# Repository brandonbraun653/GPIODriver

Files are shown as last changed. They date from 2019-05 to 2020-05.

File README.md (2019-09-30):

# GPIODriver

This project is intended to provide a low-cost USB tethered HW/SW solution for controlling a large amount of discrete IO
signals at standard aircraft voltage levels (28vdc). More will be added here as the project matures. Currently in the
prototyping phase for both the hardware and the software.

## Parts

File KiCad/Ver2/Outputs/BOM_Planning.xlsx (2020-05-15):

Description | Part Name | Package | LCSC P/N | MFR P/N | Comment
PNP Transistor (600mA, 150V) | MMBT5401 | SOT-23 | C8326 (https://lcsc.com/product-detail/Transistors-NPN-PNP_Changjiang-Electronics-Tech-CJ-MMBT5401_C8326.html/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) | MMBT5401
NPN Transistor (600mA, 160V) | MMBT5551 | SOT-23 | C2145 (https://lcsc.com/product-detail/Transistors-NPN-PNP_Changjiang-Electronics-Tech-CJ-MMBT5551_C2145.html/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) | MMBT5551
Optocouple | EL357N | SOP-4 | C29981 (https://lcsc.com/product-detail/SMD-Optocouplers_EL357N-C-TA-G_C29981.html/?href=jlc-SMT) | EL357N(C)(TA)-G | Might need to find a smaller optocouple that is a basic component
GPIO Sense SR (Parallel In/Serial Out) | 74HC165 | SOIC-16 | C5613 (https://lcsc.com/product-detail/74-Series_Nexperia_74HC165D-653_74HC165D-653_C5613.html/?href=jlc-SMT) | 74HC165D,653
GPIO Out HI Drive (Shift Register) | 74HC595 | SOIC-16 | C5947 (https://lcsc.com/product-detail/74-Series_Nexperia-74HC595D-118_C5947.html/?href=jlc-SMT) | 74HC595,118
GPIO Out LO Drive (Shift Register) | 74HC595 | SOIC-16 | C5947 (https://lcsc.com/product-detail/74-Series_Nexperia-74HC595D-118_C5947.html/?href=jlc-SMT) | 74HC595,119
Octal Buffer | 74HC244 | TSSOP-20 | C5623 (https://lcsc.com/product-detail/74-Series_Nexperia-74HC244PW-118_C5623.html) | 74HC244PW,118
Digital Switch IC | 74LVC1G3157 | SC-88 | C426706 (https://lcsc.com/product-detail/Signal-Switches-Multiplexers-Decoders_Nexperia-74LVC1G3157GW-125_C426706.html) | 74LVC1G3157GW,125
Rectification Diodes | 1N4007 | SOD-123F | C108803 (https://lcsc.com/product-detail/Diodes-General-Purpose_Shandong-Jingdao-Microelectronics-1N4007W_C108803.html) | 1N4007W
High Voltage Drive Switch | AOD409 | TO-252-2(DPAK) | C36220 (https://lcsc.com/product-detail/MOSFET_Alpha-Omega-Semicon_AOD409_Alpha-Omega-Semicon-AOS-AOD409_C36220.html) | AOD409
Board To Board Connector (Male) |  |  | C59981 (https://lcsc.com/product-detail/Pin-Header-Female-Header_BOOMELE-Boom-Precision-Elec-C59981_C59981.html)
Board To Board Connector (Female) |  |  | C124397 (https://lcsc.com/product-detail/Pin-Header-Female-Header_Ckmtw-Shenzhen-Cankemeng-C124397_C124397.html)

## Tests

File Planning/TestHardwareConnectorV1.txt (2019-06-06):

Expected Connections:
    - +3.3v Power, 5W max
    - +5.0v Power, 5W max
    - +12.0v Power, 10W max
    - Power Ground
    - Signal Ground
    - UART x2
    - SPI x1, 3 chip selects
    - I2C x2
    - 5 GPIO
    - 3-pin resistor ID variant (place near the first few pins)

Minimum # of Pins: 27

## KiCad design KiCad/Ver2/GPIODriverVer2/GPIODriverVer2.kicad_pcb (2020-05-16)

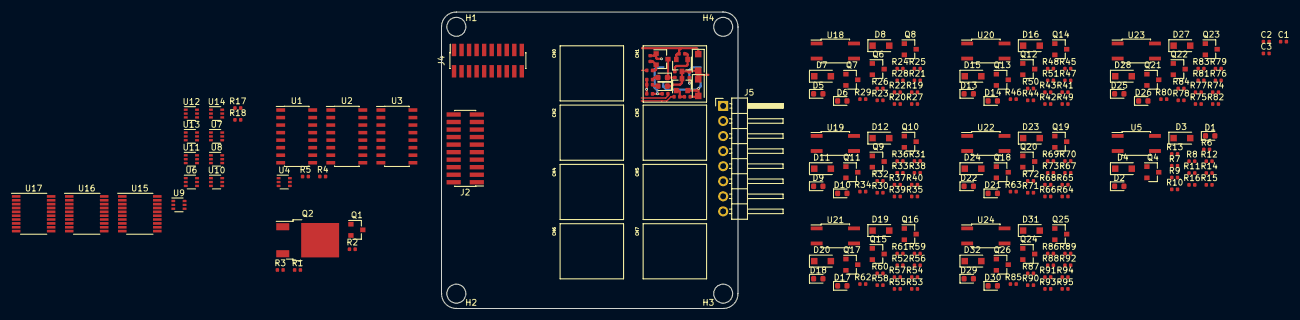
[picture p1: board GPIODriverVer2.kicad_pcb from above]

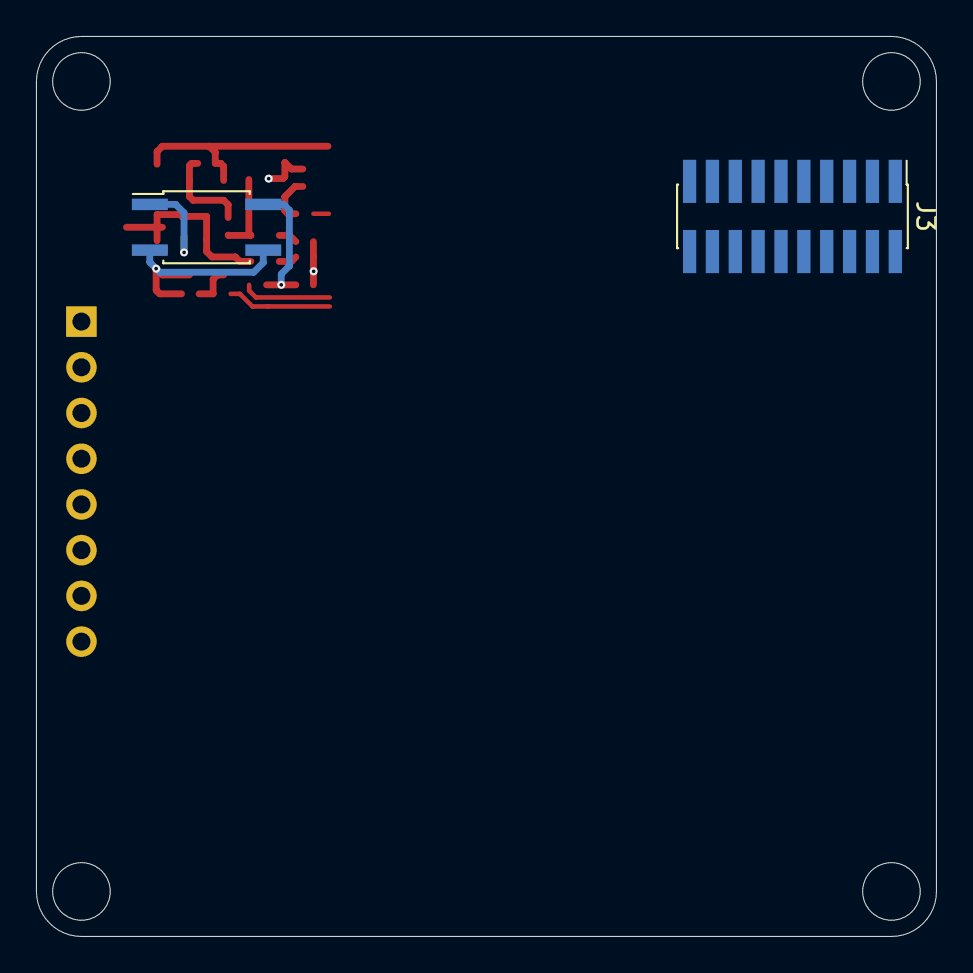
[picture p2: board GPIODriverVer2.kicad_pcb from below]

Board: 4 copper layers, 50.0 x 50.0 mm, 205 parts (2 on the bottom side), 113 nets.

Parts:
C1, C2, C3: 100nF; C_0402_1005Metric
D1, D1#2, D5, D9, D13, D17, D21, D25, D29: LED_HI_DRIVE_EN; D_0603_1608Metric
D2, D2#2, D6, D10, D14, D18, D22, D26, D30: LED_LO_DRIVE_EN; D_0603_1608Metric
D3, D3#2, D4, D4#2, D7, D8, D11, D12, D15, D16, D19, D20, D23, D24, D27, D28, D31, D32: 1N4007; D_SOD-123F
H1, H2, H3, H4: MountingHole_Pad; MountingHole_3.2mm_M3
J2: ExtInputs; PinHeader_2x10_P1.27mm_Vertical_SMD
J3: DaisyChainInput; PinHeader_2x10_P1.27mm_Vertical_SMD
J4: DaisyChainOutput; PinSocket_2x10_P1.27mm_Vertical_SMD
J5: DriveOutput; PinHeader_1x08_P2.54mm_Horizontal
Q1, Q3, Q6, Q9, Q12, Q15, Q18, Q21, Q24: 2N3904; SOT-23
Q2: AOD409; TO-252-2
Q4, Q4#2, Q7, Q10, Q13, Q16, Q19, Q22, Q25: MMBT5401; SOT-23
Q5, Q8, Q11, Q14, Q17, Q20, Q23, Q26: MMBT5551L; SOT-23
R1, R7, R7#2, R9, R9#2, R13, R13#2, R20, R22, R26, R31, R33, R37, R42, R44, R48, R53, R55, R59, R64, R66, R70, R75, R77, R81, R86, R88, R92: 100; R_0402_1005Metric
R2, R3, R4, R5, R8, R8#2, R10, R10#2, R14, R14#2, R15, R15#2, R17, R18, R21, R23, R27, R28, R32, R34, R38, R39, R43, R45, R49, R50, R54, R56, R60, R61, R65, R67, R71, R72, R76, R78, R82, R83, R87, R89, R93, R94: 10k; R_0402_1005Metric
R6, R6#2, R12, R12#2, R19, R25, R30, R36, R41, R47, R52, R58, R63, R69, R74, R80, R85, R91: 1.8k; R_0402_1005Metric
R11, R11#2, R24, R35, R46, R57, R68, R79, R90: 500; R_0402_1005Metric
R16, R16#2, R29, R40, R51, R62, R73, R84, R95: 5.6k; R_0402_1005Metric
U1: SR_WRITE_HI; SOIC-16_3.9x9.9mm_P1.27mm
U2: SR_WRITE_LO; SOIC-16_3.9x9.9mm_P1.27mm
U3: SR_READ_STATE; SOIC-16_3.9x9.9mm_P1.27mm
U4, U6, U7, U8, U9, U10, U11, U12, U13, U14: 74LVC1G3157; SOT-363_SC-70-6
U5, U5#2, U18, U19, U20, U21, U22, U23, U24: LTV-357T; SO-4_4.4x3.6mm_P2.54mm
U15, U16, U17: 74HC244; TSSOP-20_4.4x6.5mm_P0.65mm

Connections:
/DriveCircuitry/DriveChannel0/DriveOutput: D30.1, D31.2, D32.1, J5.1, Q25.3, Q26.3, R95.2
/DriveCircuitry/DriveChannel1/DriveOutput: D2.1, D2#2.1, D3.2, D3#2.2, D4.1, D4#2.1, J5.2, Q4.3, Q4#2.3, Q5.3, R16.2, R16#2.2
/DriveCircuitry/DriveChannel2/DriveOutput: D6.1, D7.2, D8.1, J5.3, Q7.3, Q8.3, R29.2
/DriveCircuitry/DriveChannel3/DriveOutput: D10.1, D11.2, D12.1, J5.4, Q10.3, Q11.3, R40.2
/DriveCircuitry/DriveChannel4/DriveOutput: D14.1, D15.2, D16.1, J5.5, Q13.3, Q14.3, R51.2
/DriveCircuitry/DriveChannel5/DriveOutput: D18.1, D19.2, D20.1, J5.6, Q16.3, Q17.3, R62.2
/DriveCircuitry/DriveChannel6/DriveOutput: D22.1, D23.2, D24.1, J5.7, Q19.3, Q20.3, R73.2
/DriveCircuitry/DriveChannel7/DriveOutput: D26.1, D27.2, D28.1, J5.8, Q22.3, Q23.3, R84.2
/InputCircuitry/EXT_3V3_PWR: J4.13, J4.15
/InputCircuitry/EXT_5V_PWR: J4.1, J4.3
/InputCircuitry/EXT_HV_PWR: J4.7, J4.9
/InputCircuitry/INT_OUTPUT_DRIVE_EN: U1.13, U2.13
/InputCircuitry/INT_SPI_RW_MOSI: U1.14, U2.14
/InputCircuitry/INT_SPI_RW_SCK: U1.11, U2.11, U3.2
/InputCircuitry/INT_SPI_W_CS_HI_DRIVE: U1.12, U4.6
CH0_HI_EN: R86.2, U1.15
CH0_LO_EN: R92.2, U2.15
CH0_STATE: R88.2, U3.11
CH1_HI_EN: R7.2, R7#2.2, U1.1
CH1_LO_EN: R13.2, R13#2.2, U2.1
CH1_STATE: R9.2, R9#2.2, U3.12
CH2_HI_EN: R20.2, U1.2
CH2_LO_EN: R26.2, U2.2
CH2_STATE: R22.2, U3.13
CH3_HI_EN: R31.2, U1.3
CH3_LO_EN: R37.2, U2.3
CH3_STATE: R33.2, U3.14
CH4_HI_EN: R42.2, U1.4
CH4_LO_EN: R48.2, U2.4
CH4_STATE: R44.2, U3.3
CH5_HI_EN: R53.2, U1.5
CH5_LO_EN: R59.2, U2.5
CH5_STATE: R55.2, U3.4
CH6_HI_EN: R64.2, U1.6
CH6_LO_EN: R70.2, U2.6
CH6_STATE: R66.2, U3.5
CH7_HI_EN: R75.2, U1.7
CH7_LO_EN: R81.2, U2.7
CH7_STATE: R77.2, U3.6
GND: C1.1, C2.1, C3.1, D4.2, D4#2.2, D8.2, D12.2, D16.2, D20.2, D24.2, D28.2, D32.2, H1.1, H2.1, H3.1, H4.1, J4.5, J4.11, J4.17, Q1.1, Q3.1, Q5.2, Q6.1, Q8.2, Q9.1, Q11.2, Q12.1, Q14.2, Q15.1, Q17.2, Q18.1, Q20.2, Q21.1, Q23.2, Q24.1, Q26.2, R3.1, R8.2, R8#2.2, R15.2, R15#2.2, R18.2, R21.2, R28.2, R32.2, R39.2, R43.2, R50.2, R54.2, R61.2, R65.2, R72.2, R76.2, R83.2, R87.2, R94.2, U1.8, U2.8, U3.8, U4.2, U5.2, U5.3, U5#2.2, U5#2.3, U6.2, U7.2, U8.2, U9.2, U10.2, U11.2, U12.2, U13.2, U14.2, U18.2, U18.3, U19.2, U19.3, U20.2, U20.3, U21.2, U21.3, U22.2, U22.3, U23.2, U23.3, U24.2, U24.3
unnamed: D1.1, D1#2.1, Q3.3, R11.2, R11#2.2
unnamed: D1.2, D1#2.2, R6.1, R6#2.1
unnamed: D2.2, D2#2.2, R12.2, R12#2.2
unnamed: D5.1, Q6.3, R24.2
unnamed: D5.2, R19.1
unnamed: D6.2, R25.2
unnamed: D9.1, Q9.3, R35.2
unnamed: D9.2, R30.1
unnamed: D10.2, R36.2
unnamed: D13.1, Q12.3, R46.2
unnamed: D13.2, R41.1
unnamed: D14.2, R47.2
unnamed: D17.1, Q15.3, R57.2
unnamed: D17.2, R52.1
unnamed: D18.2, R58.2
unnamed: D21.1, Q18.3, R68.2
unnamed: D21.2, R63.1
unnamed: D22.2, R69.2
unnamed: D25.1, Q21.3, R79.2
unnamed: D25.2, R74.1
unnamed: D26.2, R80.2
unnamed: D29.1, Q24.3, R90.2
unnamed: D29.2, R85.1
unnamed: D30.2, R91.2
unnamed: Q1.2, R1.2, R3.2
unnamed: Q1.3, Q2.2, R2.1
unnamed: Q3.2, R7.1, R7#2.1, R8.1, R8#2.1
unnamed: Q4.1, Q4#2.1, R11.1, R11#2.1, R14.2, R14#2.2
unnamed: Q5.1, R13.1, R13#2.1, R15.1, R15#2.1
unnamed: Q6.2, R20.1, R21.1
unnamed: Q7.1, R24.1, R27.2
unnamed: Q8.1, R26.1, R28.1
unnamed: Q9.2, R31.1, R32.1
unnamed: Q10.1, R35.1, R38.2
unnamed: Q11.1, R37.1, R39.1
unnamed: Q12.2, R42.1, R43.1
unnamed: Q13.1, R46.1, R49.2
unnamed: Q14.1, R48.1, R50.1
unnamed: Q15.2, R53.1, R54.1
unnamed: Q16.1, R57.1, R60.2
unnamed: Q17.1, R59.1, R61.1
unnamed: Q18.2, R64.1, R65.1
unnamed: Q19.1, R68.1, R71.2
unnamed: Q20.1, R70.1, R72.1
unnamed: Q21.2, R75.1, R76.1
unnamed: Q22.1, R79.1, R82.2
unnamed: Q23.1, R81.1, R83.1
unnamed: Q24.2, R86.1, R87.1
unnamed: Q25.1, R90.1, R93.2
unnamed: Q26.1, R92.1, R94.1
unnamed: R4.1, U2.10
unnamed: R5.1, U1.10
unnamed: R9.1, R9#2.1, R10.2, R10#2.2, U5.4, U5#2.4
unnamed: R16.1, R16#2.1, U5.1, U5#2.1
unnamed: R22.1, R23.2, U18.4
unnamed: R29.1, U18.1
unnamed: R33.1, R34.2, U19.4
unnamed: R40.1, U19.1
unnamed: R44.1, R45.2, U20.4
unnamed: R51.1, U20.1
unnamed: R55.1, R56.2, U21.4
unnamed: R62.1, U21.1
unnamed: R66.1, R67.2, U22.4
unnamed: R73.1, U22.1
unnamed: R77.1, R78.2, U23.4
unnamed: R84.1, U23.1
unnamed: R88.1, R89.2, U24.4
unnamed: R95.1, U24.1
unnamed: U1.9, U4.3
unnamed: U2.9, U4.1
SRC_SELECT: U6.6, U7.6, U8.6, U9.6, U10.6, U11.6, U12.6, U13.6, U14.6
VBUS: D3.1, D3#2.1, D7.1, D11.1, D15.1, D19.1, D23.1, D27.1, D31.1, Q2.1, Q4.2, Q4#2.2, Q7.2, Q10.2, Q13.2, Q16.2, Q19.2, Q22.2, Q25.2, R14.1, R14#2.1, R27.1, R38.1, R49.1, R60.1, R71.1, R82.1, R93.1
VCC: C1.2, C2.2, C3.2, Q2.3, R2.2, R4.2, R5.2, R6.2, R6#2.2, R10.1, R10#2.1, R12.1, R12#2.1, R17.1, R19.2, R23.1, R25.1, R30.2, R34.1, R36.1, R41.2, R45.1, R47.1, R52.2, R56.1, R58.1, R63.2, R67.1, R69.1, R74.2, R78.1, R80.1, R85.2, R89.1, R91.1, U1.16, U2.16, U3.16, U4.5, U6.5, U7.5, U8.5, U9.5, U10.5, U11.5, U12.5, U13.5, U14.5

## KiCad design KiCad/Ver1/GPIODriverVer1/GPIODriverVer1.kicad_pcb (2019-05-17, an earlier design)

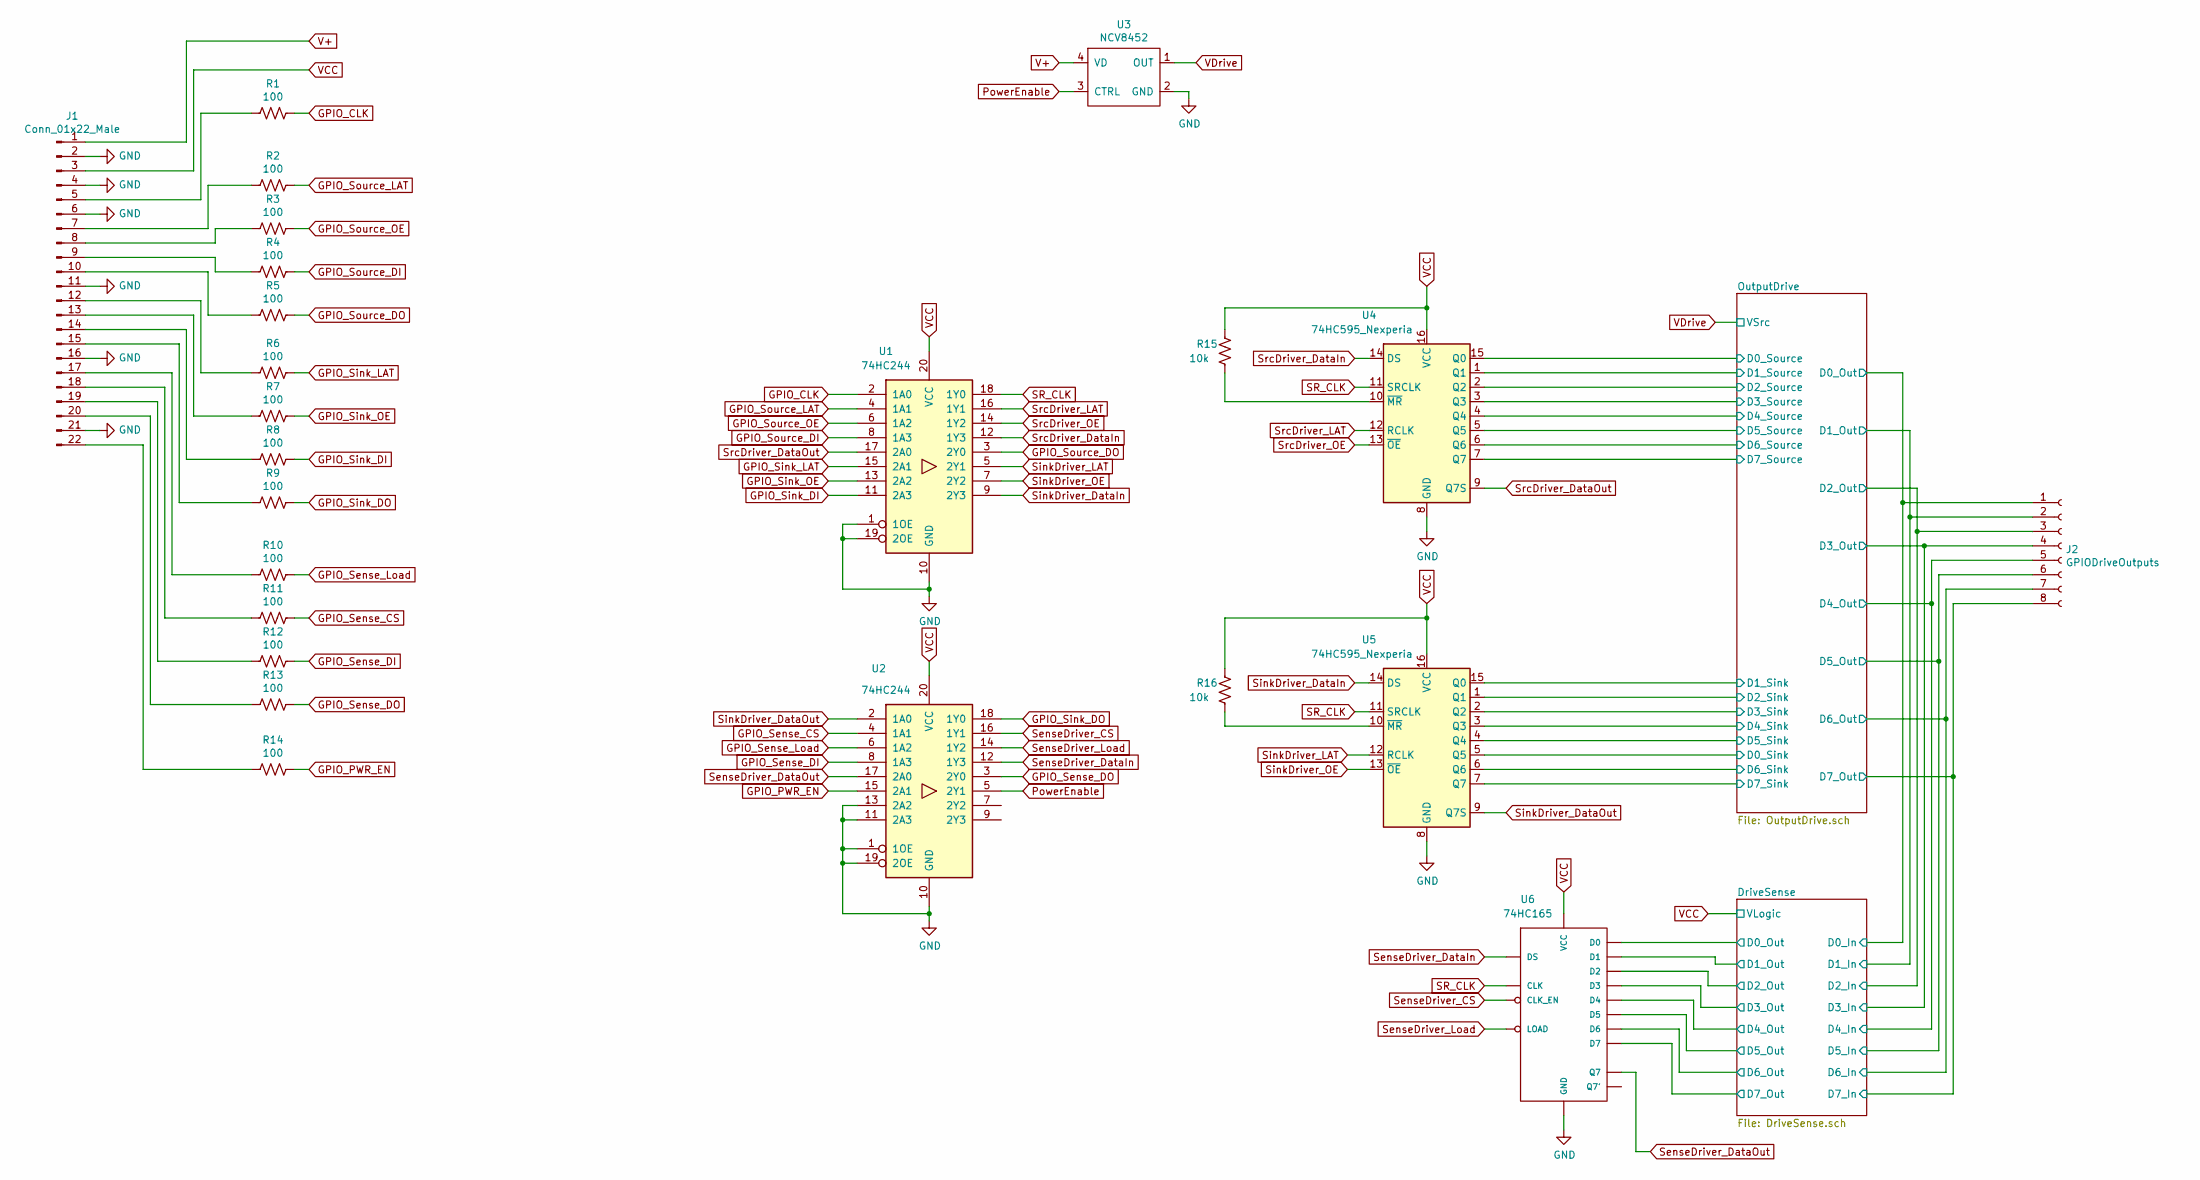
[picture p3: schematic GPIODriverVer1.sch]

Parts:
J1: Conn_01x22_Male; PinHeader_2x11_P2.54mm_Vertical
J2: GPIODriveOutputs; PinHeader_1x08_P2.54mm_Horizontal
R1, R2, R3, R4, R5, R6, R7, R8, R9, R10, R11, R12, R13, R14: 100; R_0402_1005Metric
R15, R16: 10k; R_0402_1005Metric
U1, U2: 74HC244; TSSOP-20_4.4x6.5mm_P0.65mm
U3: NCV8452; SOT-223
U4, U5: 74HC595_Nexperia; TSSOP-16_4.4x5mm_P0.65mm
U6: 74HC165; TSSOP-16_4.4x5mm_P0.65mm

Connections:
/DriveSense/D0_In: J2.1; also elsewhere on the board
/DriveSense/D0_Out: U6.11 (D0); also elsewhere on the board
/DriveSense/D1_In: J2.2; also elsewhere on the board
/DriveSense/D1_Out: U6.12 (D1); also elsewhere on the board
/DriveSense/D2_In: J2.3; also elsewhere on the board
/DriveSense/D2_Out: U6.13 (D2); also elsewhere on the board
/DriveSense/D3_In: J2.4; also elsewhere on the board
/DriveSense/D3_Out: U6.14 (D3); also elsewhere on the board
/DriveSense/D4_In: J2.5; also elsewhere on the board
/DriveSense/D4_Out: U6.3 (D4); also elsewhere on the board
/DriveSense/D5_In: J2.6; also elsewhere on the board
/DriveSense/D5_Out: U6.4 (D5); also elsewhere on the board
/DriveSense/D6_In: J2.7; also elsewhere on the board
/DriveSense/D6_Out: U6.5 (D6); also elsewhere on the board
/DriveSense/D7_In: J2.8; also elsewhere on the board
/DriveSense/D7_Out: U6.6 (D7); also elsewhere on the board
/OutputDrive/D0_Sink: U5.5 (Q5); also elsewhere on the board
/OutputDrive/D0_Source: U4.15 (Q0); also elsewhere on the board
/OutputDrive/D1_Sink: U5.15 (Q0); also elsewhere on the board
/OutputDrive/D1_Source: U4.1 (Q1); also elsewhere on the board
/OutputDrive/D2_Sink: U5.1 (Q1); also elsewhere on the board
/OutputDrive/D2_Source: U4.2 (Q2); also elsewhere on the board
/OutputDrive/D3_Sink: U5.2 (Q2); also elsewhere on the board
/OutputDrive/D3_Source: U4.3 (Q3); also elsewhere on the board
/OutputDrive/D4_Sink: U5.3 (Q3); also elsewhere on the board
/OutputDrive/D4_Source: U4.4 (Q4); also elsewhere on the board
/OutputDrive/D5_Sink: U5.4 (Q4); also elsewhere on the board
/OutputDrive/D5_Source: U4.5 (Q5); also elsewhere on the board
/OutputDrive/D6_Sink: U5.6 (Q6); also elsewhere on the board
/OutputDrive/D6_Source: U4.6 (Q6); also elsewhere on the board
/OutputDrive/D7_Sink: U5.7 (Q7); also elsewhere on the board
/OutputDrive/D7_Source: U4.7 (Q7); also elsewhere on the board
GND: J1.2, J1.4, J1.6, J1.11, J1.16, J1.21, U1.1 (1OE), U1.10 (GND), U1.19 (2OE), U2.1 (1OE), U2.10 (GND), U2.11 (2A3), U2.13 (2A2), U2.19 (2OE), U3.2 (GND), U4.8 (GND), U5.8 (GND), U6.8 (GND); also elsewhere on the board
GPIO_CLK: R1.1, U1.2 (1A0)
GPIO_PWR_EN: R14.1, U2.15 (2A1)
GPIO_Sense_CS: R11.1, U2.4 (1A1)
GPIO_Sense_DI: R12.1, U2.8 (1A3)
GPIO_Sense_DO: R13.1, U2.3 (2Y0)
GPIO_Sense_Load: R10.1, U2.6 (1A2)
GPIO_Sink_DI: R8.1, U1.11 (2A3)
GPIO_Sink_DO: R9.1, U2.18 (1Y0)
GPIO_Sink_LAT: R6.1, U1.15 (2A1)
GPIO_Sink_OE: R7.1, U1.13 (2A2)
GPIO_Source_DI: R4.1, U1.8 (1A3)
GPIO_Source_DO: R5.1, U1.3 (2Y0)
GPIO_Source_LAT: R2.1, U1.4 (1A1)
GPIO_Source_OE: R3.1, U1.6 (1A2)
unnamed: J1.5, R1.2
unnamed: J1.7, R2.2
unnamed: J1.8, R3.2
unnamed: J1.9, R4.2
unnamed: J1.10, R5.2
unnamed: J1.12, R6.2
unnamed: J1.13, R7.2
unnamed: J1.14, R8.2
unnamed: J1.15, R9.2
unnamed: J1.17, R10.2
unnamed: J1.18, R11.2
unnamed: J1.19, R12.2
unnamed: J1.20, R13.2
unnamed: J1.22, R14.2
unnamed: R15.1, U4.10 (~MR)
unnamed: R16.1, U5.10 (~MR)
PowerEnable: U2.5 (2Y1), U3.3 (CTRL)
SR_CLK: U1.18 (1Y0), U4.11 (SRCLK), U5.11 (SRCLK), U6.2 (CLK)
SenseDriver_CS: U2.16 (1Y1), U6.15 (CLK_EN)
SenseDriver_DataIn: U2.12 (1Y3), U6.10 (DS)
SenseDriver_DataOut: U2.17 (2A0), U6.9 (Q7)
SenseDriver_Load: U2.14 (1Y2), U6.1 (LOAD)
SinkDriver_DataIn: U1.9 (2Y3), U5.14 (DS)
SinkDriver_DataOut: U2.2 (1A0), U5.9 (Q7S)
SinkDriver_LAT: U1.5 (2Y1), U5.12 (RCLK)
SinkDriver_OE: U1.7 (2Y2), U5.13 (~OE)
SrcDriver_DataIn: U1.12 (1Y3), U4.14 (DS)
SrcDriver_DataOut: U1.17 (2A0), U4.9 (Q7S)
SrcDriver_LAT: U1.16 (1Y1), U4.12 (RCLK)
SrcDriver_OE: U1.14 (1Y2), U4.13 (~OE)
V+: J1.1, U3.4 (VD)
VCC: J1.3, R15.2, R16.2, U1.20 (VCC), U2.20 (VCC), U4.16 (VCC), U5.16 (VCC), U6.16 (VCC); also elsewhere on the board
VDrive: U3.1 (OUT); also elsewhere on the board

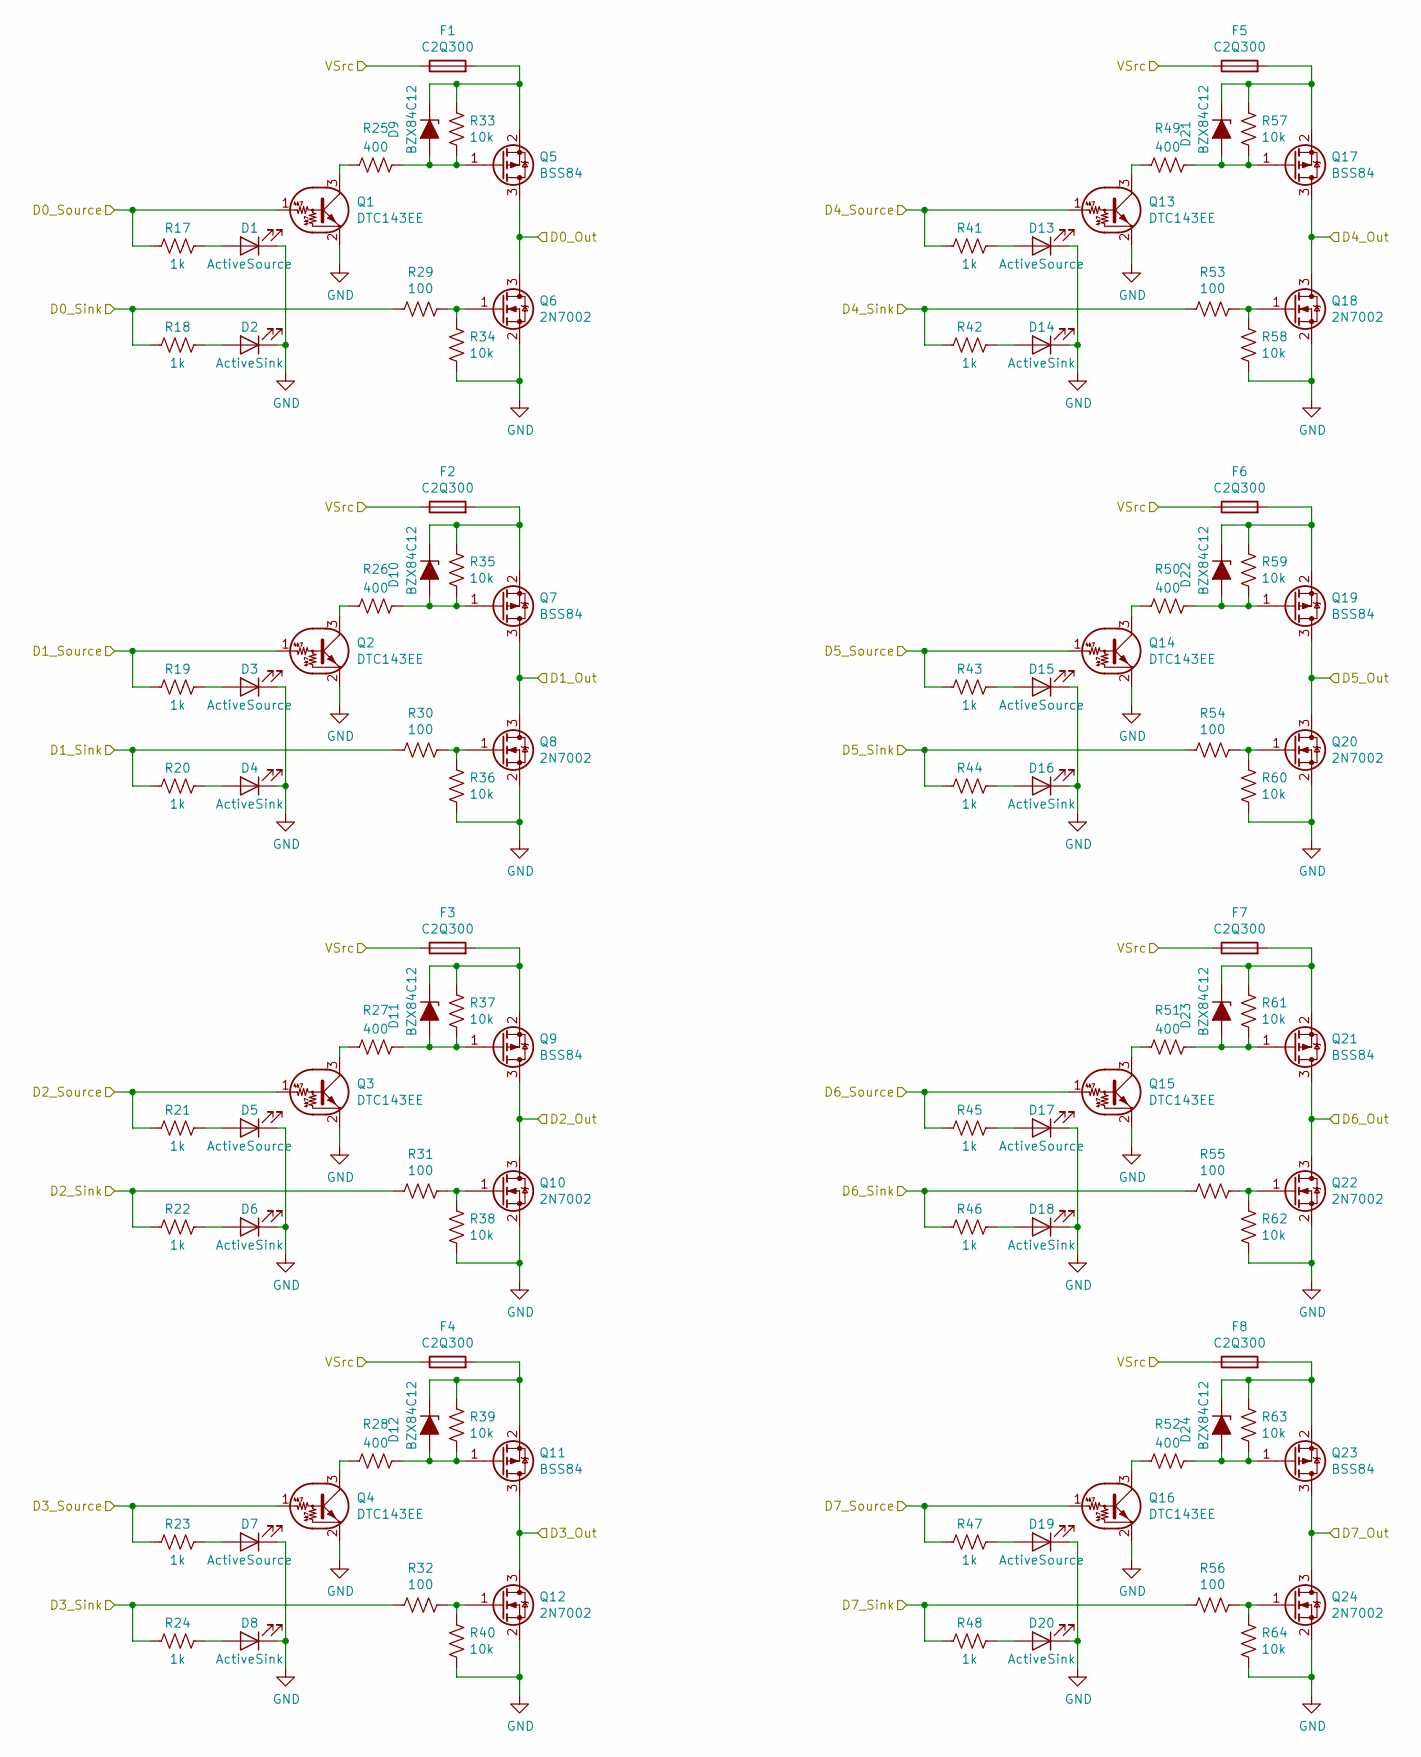
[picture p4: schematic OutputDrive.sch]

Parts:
D1, D3, D5, D7, D13, D15, D17, D19: ActiveSource; D_0603_1608Metric_Pad1.05x0.95mm_HandSolder
D2, D4, D6, D8, D14, D16, D18, D20: ActiveSink; D_0603_1608Metric_Pad1.05x0.95mm_HandSolder
D9, D10, D11, D12, D21, D22, D23, D24: BZX84C12; D_SOT-23_ANK
F1, F2, F3, F4, F5, F6, F7, F8: C2Q300; R_0603_1608Metric
Q1, Q2, Q3, Q4, Q13, Q14, Q15, Q16: DTC143EE; SOT-723
Q5, Q7, Q9, Q11, Q17, Q19, Q21, Q23: BSS84; SOT-323_SC-70
Q6, Q8, Q10, Q12, Q18, Q20, Q22, Q24: 2N7002; SOT-23
R17, R18, R19, R20, R21, R22, R23, R24, R41, R42, R43, R44, R45, R46, R47, R48: 1k; R_0402_1005Metric
R25, R26, R27, R28, R49, R50, R51, R52: 400; R_0402_1005Metric
R29, R30, R31, R32, R53, R54, R55, R56: 100; R_0402_1005Metric
R33, R34, R35, R36, R37, R38, R39, R40, R57, R58, R59, R60, R61, R62, R63, R64: 10k; R_0402_1005Metric

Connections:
/DriveSense/D0_In: Q5.3 (D), Q6.3 (D); also elsewhere on the board
/DriveSense/D1_In: Q7.3 (D), Q8.3 (D); also elsewhere on the board
/DriveSense/D2_In: Q9.3 (D), Q10.3 (D); also elsewhere on the board
/DriveSense/D3_In: Q11.3 (D), Q12.3 (D); also elsewhere on the board
/DriveSense/D4_In: Q17.3 (D), Q18.3 (D); also elsewhere on the board
/DriveSense/D5_In: Q19.3 (D), Q20.3 (D); also elsewhere on the board
/DriveSense/D6_In: Q21.3 (D), Q22.3 (D); also elsewhere on the board
/DriveSense/D7_In: Q23.3 (D), Q24.3 (D); also elsewhere on the board
/OutputDrive/D0_Sink: R18.2, R29.2; also elsewhere on the board
/OutputDrive/D0_Source: Q1.1 (B), R17.2; also elsewhere on the board
/OutputDrive/D1_Sink: R20.2, R30.2; also elsewhere on the board
/OutputDrive/D1_Source: Q2.1 (B), R19.2; also elsewhere on the board
/OutputDrive/D2_Sink: R22.2, R31.2; also elsewhere on the board
/OutputDrive/D2_Source: Q3.1 (B), R21.2; also elsewhere on the board
/OutputDrive/D3_Sink: R24.2, R32.2; also elsewhere on the board
/OutputDrive/D3_Source: Q4.1 (B), R23.2; also elsewhere on the board
/OutputDrive/D4_Sink: R42.2, R53.2; also elsewhere on the board
/OutputDrive/D4_Source: Q13.1 (B), R41.2; also elsewhere on the board
/OutputDrive/D5_Sink: R44.2, R54.2; also elsewhere on the board
/OutputDrive/D5_Source: Q14.1 (B), R43.2; also elsewhere on the board
/OutputDrive/D6_Sink: R46.2, R55.2; also elsewhere on the board
/OutputDrive/D6_Source: Q15.1 (B), R45.2; also elsewhere on the board
/OutputDrive/D7_Sink: R48.2, R56.2; also elsewhere on the board
/OutputDrive/D7_Source: Q16.1 (B), R47.2; also elsewhere on the board
GND: D1.1 (K), D2.1 (K), D3.1 (K), D4.1 (K), D5.1 (K), D6.1 (K), D7.1 (K), D8.1 (K), D13.1 (K), D14.1 (K), D15.1 (K), D16.1 (K), D17.1 (K), D18.1 (K), D19.1 (K), D20.1 (K), Q1.2 (E), Q2.2 (E), Q3.2 (E), Q4.2 (E), Q6.2 (S), Q8.2 (S), Q10.2 (S), Q12.2 (S), Q13.2 (E), Q14.2 (E), Q15.2 (E), Q16.2 (E), Q18.2 (S), Q20.2 (S), Q22.2 (S), Q24.2 (S), R34.1, R36.1, R38.1, R40.1, R58.1, R60.1, R62.1, R64.1; also elsewhere on the board
unnamed: D1.2 (A), R17.1
unnamed: D2.2 (A), R18.1
unnamed: D3.2 (A), R19.1
unnamed: D4.2 (A), R20.1
unnamed: D5.2 (A), R21.1
unnamed: D6.2 (A), R22.1
unnamed: D7.2 (A), R23.1
unnamed: D8.2 (A), R24.1
unnamed: D9.1 (K), F1.2, Q5.2 (S), R33.1
unnamed: D9.2 (A), Q5.1 (G), R25.2, R33.2
unnamed: D10.1 (K), F2.2, Q7.2 (S), R35.1
unnamed: D10.2 (A), Q7.1 (G), R26.2, R35.2
unnamed: D11.1 (K), F3.2, Q9.2 (S), R37.1
unnamed: D11.2 (A), Q9.1 (G), R27.2, R37.2
unnamed: D12.1 (K), F4.2, Q11.2 (S), R39.1
unnamed: D12.2 (A), Q11.1 (G), R28.2, R39.2
unnamed: D13.2 (A), R41.1
unnamed: D14.2 (A), R42.1
unnamed: D15.2 (A), R43.1
unnamed: D16.2 (A), R44.1
unnamed: D17.2 (A), R45.1
unnamed: D18.2 (A), R46.1
unnamed: D19.2 (A), R47.1
unnamed: D20.2 (A), R48.1
unnamed: D21.1 (K), F5.2, Q17.2 (S), R57.1
unnamed: D21.2 (A), Q17.1 (G), R49.2, R57.2
unnamed: D22.1 (K), F6.2, Q19.2 (S), R59.1
unnamed: D22.2 (A), Q19.1 (G), R50.2, R59.2
unnamed: D23.1 (K), F7.2, Q21.2 (S), R61.1
unnamed: D23.2 (A), Q21.1 (G), R51.2, R61.2
unnamed: D24.1 (K), F8.2, Q23.2 (S), R63.1
unnamed: D24.2 (A), Q23.1 (G), R52.2, R63.2
unnamed: Q1.3 (C), R25.1
unnamed: Q2.3 (C), R26.1
unnamed: Q3.3 (C), R27.1
unnamed: Q4.3 (C), R28.1
unnamed: Q6.1 (G), R29.1, R34.2
unnamed: Q8.1 (G), R30.1, R36.2
unnamed: Q10.1 (G), R31.1, R38.2
unnamed: Q12.1 (G), R32.1, R40.2
unnamed: Q13.3 (C), R49.1
unnamed: Q14.3 (C), R50.1
unnamed: Q15.3 (C), R51.1
unnamed: Q16.3 (C), R52.1
unnamed: Q18.1 (G), R53.1, R58.2
unnamed: Q20.1 (G), R54.1, R60.2
unnamed: Q22.1 (G), R55.1, R62.2
unnamed: Q24.1 (G), R56.1, R64.2
VDrive: F1.1, F2.1, F3.1, F4.1, F5.1, F6.1, F7.1, F8.1; also elsewhere on the board

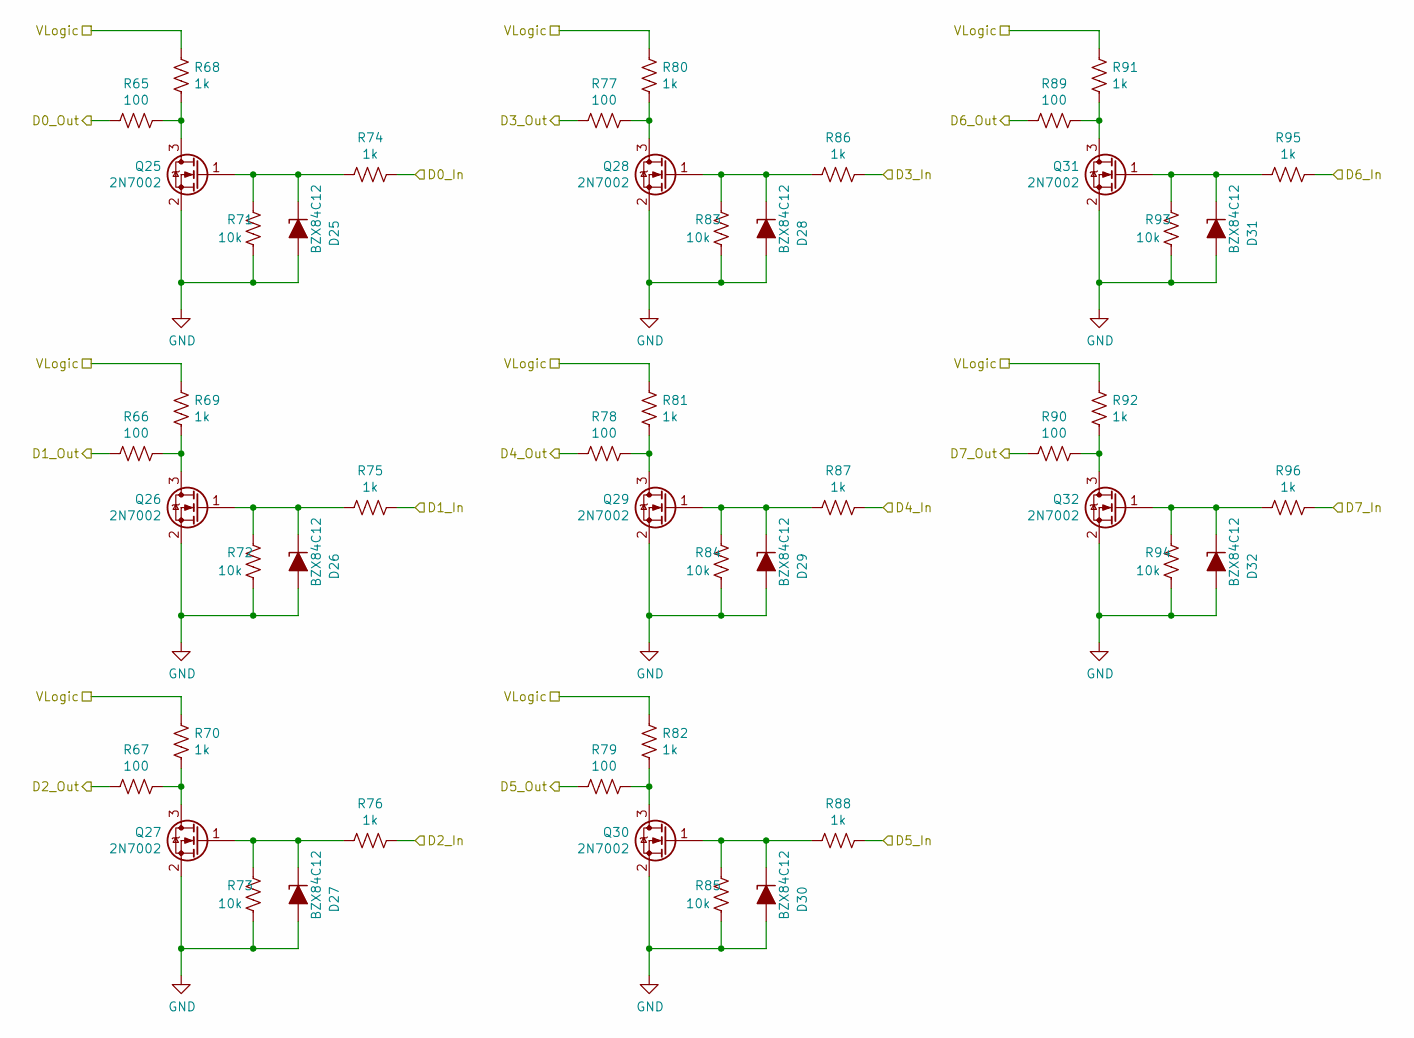
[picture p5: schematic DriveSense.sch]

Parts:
D25, D26, D27, D28, D29, D30, D31, D32: BZX84C12; D_SOT-23_ANK
Q25, Q26, Q27, Q28, Q29, Q30, Q31, Q32: 2N7002; SOT-23
R65, R66, R67, R77, R78, R79, R89, R90: 100; R_0402_1005Metric
R68, R69, R70, R74, R75, R76, R80, R81, R82, R86, R87, R88, R91, R92, R95, R96: 1k; R_0402_1005Metric
R71, R72, R73, R83, R84, R85, R93, R94: 10k; R_0402_1005Metric

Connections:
/DriveSense/D0_In: R74.1; also elsewhere on the board
/DriveSense/D0_Out: R65.2; also elsewhere on the board
/DriveSense/D1_In: R75.1; also elsewhere on the board
/DriveSense/D1_Out: R66.2; also elsewhere on the board
/DriveSense/D2_In: R76.1; also elsewhere on the board
/DriveSense/D2_Out: R67.2; also elsewhere on the board
/DriveSense/D3_In: R86.1; also elsewhere on the board
/DriveSense/D3_Out: R77.2; also elsewhere on the board
/DriveSense/D4_In: R87.1; also elsewhere on the board
/DriveSense/D4_Out: R78.2; also elsewhere on the board
/DriveSense/D5_In: R88.1; also elsewhere on the board
/DriveSense/D5_Out: R79.2; also elsewhere on the board
/DriveSense/D6_In: R95.1; also elsewhere on the board
/DriveSense/D6_Out: R89.2; also elsewhere on the board
/DriveSense/D7_In: R96.1; also elsewhere on the board
/DriveSense/D7_Out: R90.2; also elsewhere on the board
GND: D25.2 (A), D26.2 (A), D27.2 (A), D28.2 (A), D29.2 (A), D30.2 (A), D31.2 (A), D32.2 (A), Q25.2 (S), Q26.2 (S), Q27.2 (S), Q28.2 (S), Q29.2 (S), Q30.2 (S), Q31.2 (S), Q32.2 (S), R71.2, R72.2, R73.2, R83.2, R84.2, R85.2, R93.2, R94.2; also elsewhere on the board
unnamed: D25.1 (K), Q25.1 (G), R71.1, R74.2
unnamed: D26.1 (K), Q26.1 (G), R72.1, R75.2
unnamed: D27.1 (K), Q27.1 (G), R73.1, R76.2
unnamed: D28.1 (K), Q28.1 (G), R83.1, R86.2
unnamed: D29.1 (K), Q29.1 (G), R84.1, R87.2
unnamed: D30.1 (K), Q30.1 (G), R85.1, R88.2
unnamed: D31.1 (K), Q31.1 (G), R93.1, R95.2
unnamed: D32.1 (K), Q32.1 (G), R94.1, R96.2
unnamed: Q25.3 (D), R65.1, R68.2
unnamed: Q26.3 (D), R66.1, R69.2
unnamed: Q27.3 (D), R67.1, R70.2
unnamed: Q28.3 (D), R77.1, R80.2
unnamed: Q29.3 (D), R78.1, R81.2
unnamed: Q30.3 (D), R79.1, R82.2
unnamed: Q31.3 (D), R89.1, R91.2
unnamed: Q32.3 (D), R90.1, R92.2
VCC: R68.1, R69.1, R70.1, R80.1, R81.1, R82.1, R91.1, R92.1; also elsewhere on the board

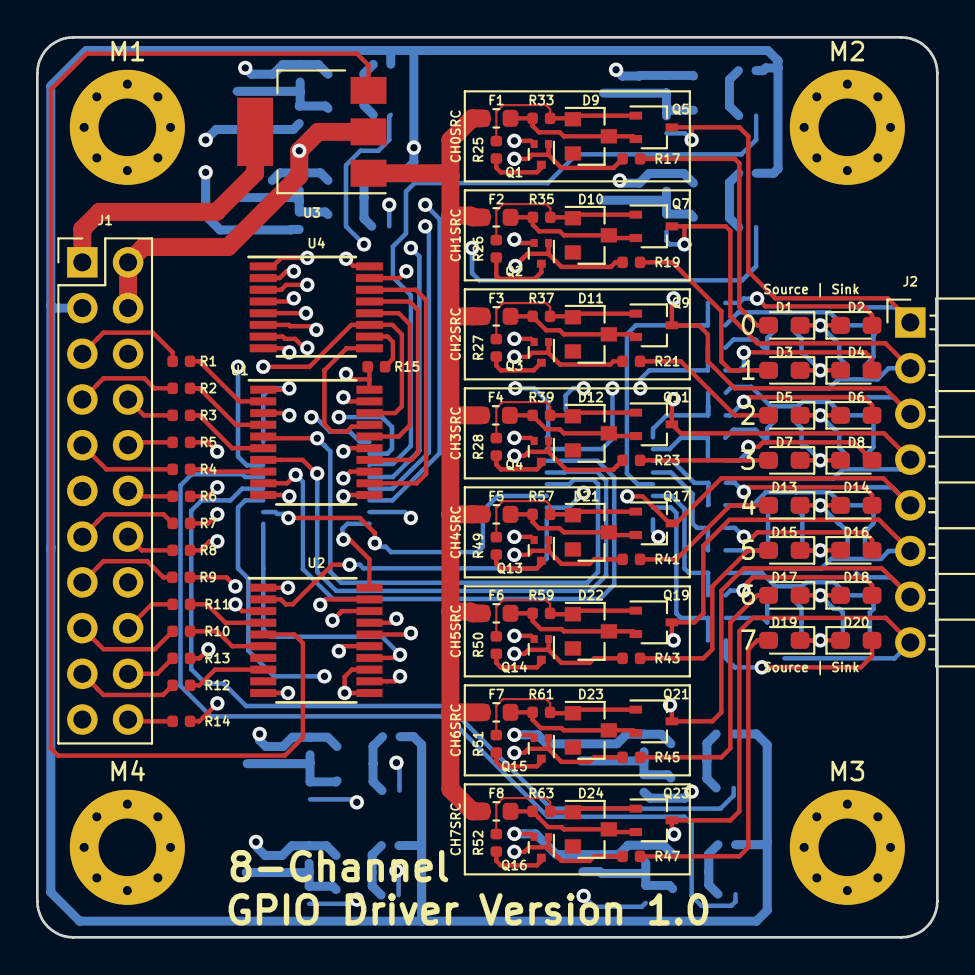
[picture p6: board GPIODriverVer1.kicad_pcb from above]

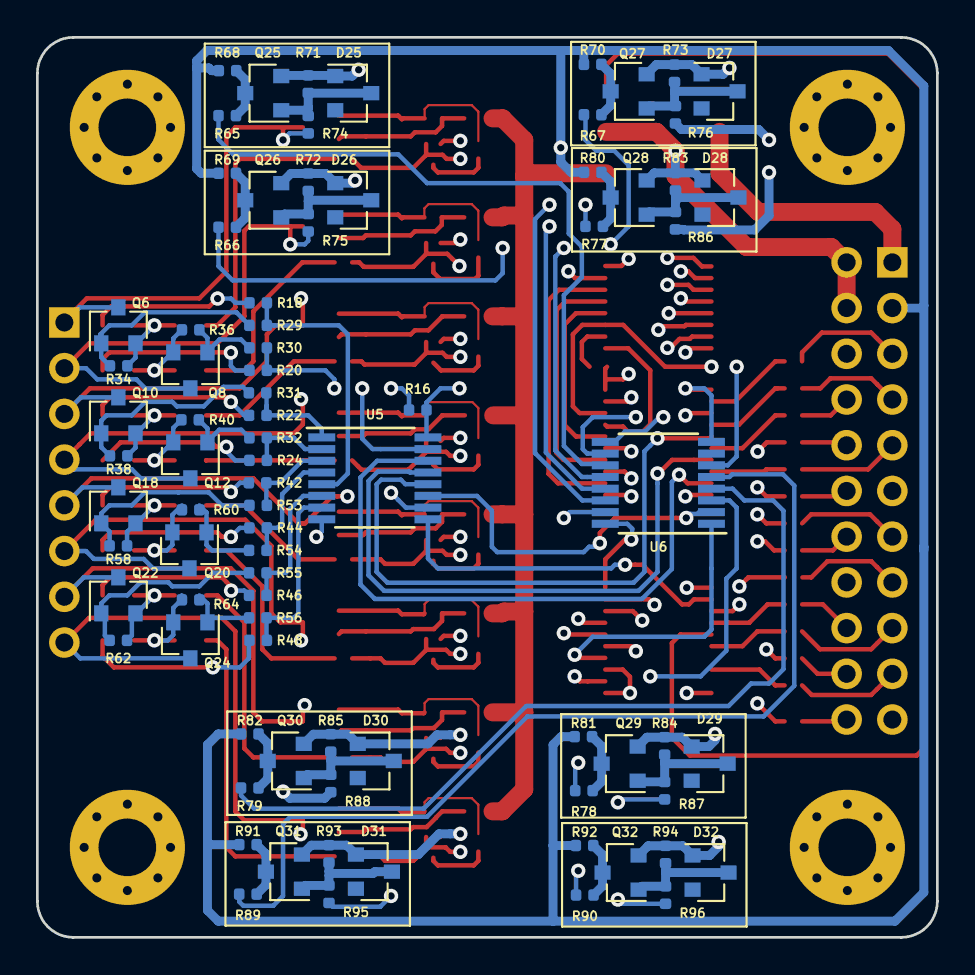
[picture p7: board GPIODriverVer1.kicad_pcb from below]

Board: 4 copper layers, 50.0 x 50.0 mm, 180 parts (83 on the bottom side), 144 nets.

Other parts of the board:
M1, M2, M3, M4: MountingHole_3.2mm_M3_Pad_Via

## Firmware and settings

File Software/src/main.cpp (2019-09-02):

/********************************************************************************
 *  File Name:
 *    main.cpp
 * 
 *  Description:
 *    Entry point to the GPIO Driver system image
 *
 *  2019 | Brandon Braun | brandonbraun653@gmail.com
 ********************************************************************************/

/* C++ Includes */


/* Chimera Includes */
#include <Chimera/chimera.hpp>
#include <Chimera/system.hpp>
#include <Chimera/threading.hpp>
#include <Chimera/watchdog.hpp>

/* Project Includes */
#include <io_resources.hpp>
#include <system_threads.hpp>

using namespace Chimera;
using namespace Chimera::Threading;
using namespace GPIODriver;

int main()
{
  Chimera::System::initialize();
  Thread::handle.fill( nullptr );

  addThread( Thread::DebugSandboxThread, "sandbox", 1000, nullptr, 2, &Thread::handle[ Thread::ID::SANDBOX_THREAD ] );
  addThread( Thread::BootUpThread, "boot", 500, nullptr, 2, &Thread::handle[ Thread::ID::BOOT_THREAD ] );
  addThread( Thread::HeartbeatThread, "heartbeat", 100, nullptr, 2, &Thread::handle[ Thread::ID::HEARTBEAT_THREAD ] );


  startScheduler();

  /*------------------------------------------------
  Should never get here. If we do, allow the watchdog to reset the board.
  ------------------------------------------------*/
  //Watchdog::invokeTimeout();
  return 0;
}

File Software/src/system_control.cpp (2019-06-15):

/********************************************************************************
 *   File Name:
 *    system_control.cpp
 *
 *   Description:
 *    Implements very low level functionality to control the system hardware
 *
 *   2019 | Brandon Braun | brandonbraun653@gmail.com
 ********************************************************************************/

/* Chimera Includes */
#include <Chimera/gpio.hpp>
#include <Chimera/spi.hpp>

/* Project Includes */
#include <system_control.hpp>
#include <system_hardware.hpp>

namespace GPIODriver
{
  namespace Power
  {
    Chimera::Status_t enable()
    {
      return GPIODriver::HW::GPIO::powerEnable->setState( Chimera::GPIO::State::HIGH );
    }

    Chimera::Status_t disable()
    {
      return GPIODriver::HW::GPIO::powerEnable->setState( Chimera::GPIO::State::LOW );
    }
  }

  namespace Source
  {
    Chimera::Status_t enable()
    {
      /* OE pin is active low */
      return GPIODriver::HW::GPIO::sourceDriverOE->setState( Chimera::GPIO::State::LOW );
    }

    Chimera::Status_t disable()
    {
      /* OE pin is active low */
      return GPIODriver::HW::GPIO::sourceDriverOE->setState( Chimera::GPIO::State::HIGH );
    }

    Chimera::Status_t write( const uint8_t *const data, const size_t size )
    {
      Chimera::Status_t result = Chimera::CommonStatusCodes::FAIL;

      GPIODriver::HW::SPI::cs0->setState( Chimera::GPIO::State::LOW );
      result = GPIODriver::HW::SPI::instance->writeBytes( data, size, 500 );
      GPIODriver::HW::SPI::cs0->setState( Chimera::GPIO::State::HIGH );

      return result;
    }
  }

  namespace Sink
  {
    Chimera::Status_t enable()
    {
      /* OE pin is active low */
      return GPIODriver::HW::GPIO::sinkDriverOE->setState( Chimera::GPIO::State::LOW );
    }

    Chimera::Status_t disable()
    {
      /* OE pin is active low */
      return GPIODriver::HW::GPIO::sinkDriverOE->setState( Chimera::GPIO::State::HIGH );
    }

    Chimera::Status_t write( const uint8_t *const data, const size_t size )
    {
      Chimera::Status_t result = Chimera::CommonStatusCodes::FAIL;

      GPIODriver::HW::SPI::cs1->setState( Chimera::GPIO::State::LOW );
      result = GPIODriver::HW::SPI::instance->writeBytes( data, size, 500 );
      GPIODriver::HW::SPI::cs1->setState( Chimera::GPIO::State::HIGH );

      return result;
    }
  }

  namespace Sense
  {
    Chimera::Status_t read( uint8_t *const data, const size_t size )
    {

    }
  }
}

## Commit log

2019-04-21 Added the driver ver 1 project
    [DriveSense.sch, GPIODriverVer1.kicad_pcb, GPIODriverVer1.sch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]
2019-04-21 Updated schematic to include input/output buffers. Added connections for shift registers.
    [DriveSense.sch, GPIODriverVer1.sch, OutputDrive.sch]
2019-04-23 Save point Ver1 design.
    [DriveSense.sch, GPIODriverVer1.sch, OutputDrive.sch]
2019-04-25 Save progress for this week
    [GPIODriverVer1.kicad_pcb]
2019-05-07 Updated board with possible sink driver layout.
    [GPIODriverVer1.kicad_pcb]
2019-05-09 Routed the current sink driver primitives.
    [GPIODriverVer1.kicad_pcb]
2019-05-10 Fanned out/organized the sense circuit
    [GPIODriverVer1.kicad_pcb]
2019-05-12 Fully routed Rev 1.0 Prototype Board
    [GPIODriverVer1-B_Cu.gbr, GPIODriverVer1-B_Mask.gbr, GPIODriverVer1-B_Paste.gbr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]
2019-05-17 Update gerbers.
    [GPIODriverVer1-B_Cu.gbr, GPIODriverVer1-B_Mask.gbr, GPIODriverVer1-B_Paste.gbr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]
2019-06-12 Added low level hardware initialization functions/threads. Created new embedded driver VisualGDB project. Submodule update.
    [GPIODriverVer1BOM.csv]
2019-06-13 Switched the serial objects to run in interrupt mode and finished the prototype init routines.
2019-06-15 Driver updates. Added new items to the project.
2019-06-16 Swapped pin location of CS1. On the Nucleo board used for development, it cannot be controlled due to connected PCB components.
    [thread_debug_sandbox.cpp]
2019-09-02 Rebase onto Thor custom driver backend for Chimera. Barebones working serial TX with DMA.
2019-09-30 Re-enabled watchdog thread after driver updates.
2020-05-14 Planned a little more of the Version 2 board.
    [BOM_Planning.xlsx, GPIODriverVer1.sch]
2020-05-15 Started working on Version 2 of the PCB. Added KiCAD component library submodule.
    [BOM_Planning.xlsx, DriveChannel1.sch, DriveCircuitry.sch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]
2020-05-16 Add sheets for output drive channels.
    [DriveChannel0.sch, DriveChannel2.sch, DriveChannel2sch.sch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]
